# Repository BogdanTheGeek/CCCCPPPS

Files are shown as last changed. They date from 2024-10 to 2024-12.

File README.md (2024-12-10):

# Cheap Crappy Constant Current Portable Programmable Power Supply 

`CCCCPPPS` is a DIY Programmable Buck/Boost Power Supply, designed with the goal
of being cheap, crappy, but very useful!  

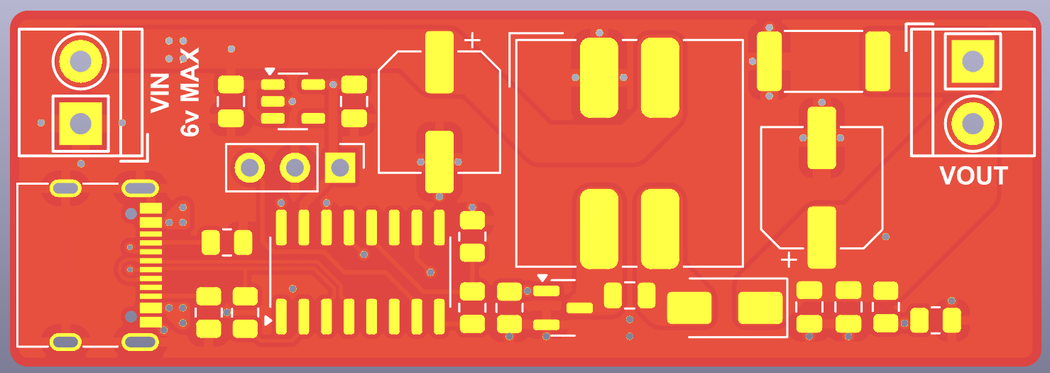
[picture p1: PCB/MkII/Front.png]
PCB_Front
  
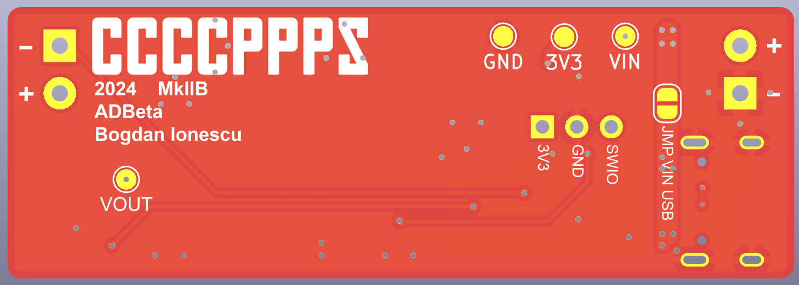
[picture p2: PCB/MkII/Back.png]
PCB_Back
  
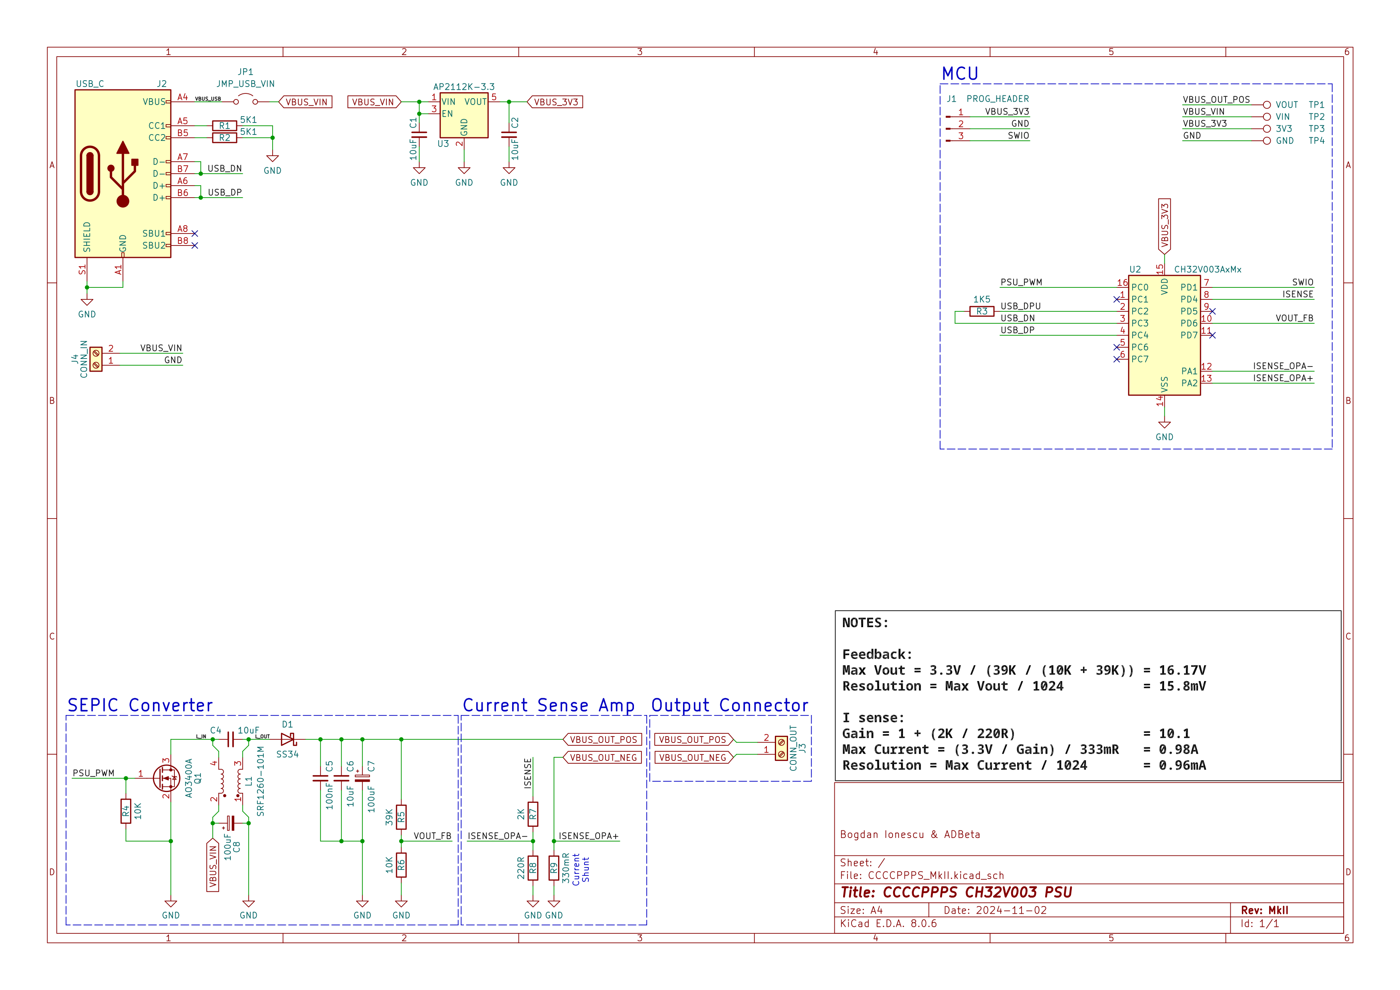
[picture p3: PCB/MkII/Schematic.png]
PCB_Schem
  

# Usage
## Web UI
https://bogdanthegeek.github.io/CCCCPPPS/software/webui/index.html
## Debug Interface:
This interface is enabled by default when building the firmware. Use `minichlink`
to issue commands listed below

## Commands
> [!NOTE]
> Need to improve the command list and handler

- `0` to turn the supply off
- `1-9` to set the target Voltage/Current in multiples of 1000mV/100mA
- `c` to switch to Constant Current Mode 
- `v` to switch to Constant Voltage Mode
- `+` to increase the target Voltage/Current depending on mode, in 50mV/25mA increments
- `-` to decrease the target Voltage/Current depending on mode, in 50mV/25mA increments
- ~~Konami code makes the unit self distruct.~~ Removed due to misuse.

# Build
```sh
export CH32V003FUN="path/to/ch32v003fun"
make
```

----
(c) 2024  
[Bogdan Ionescu](https://github.com/BogdanTheGeek)  
[ADBeta](https://github.com/ADBeta)

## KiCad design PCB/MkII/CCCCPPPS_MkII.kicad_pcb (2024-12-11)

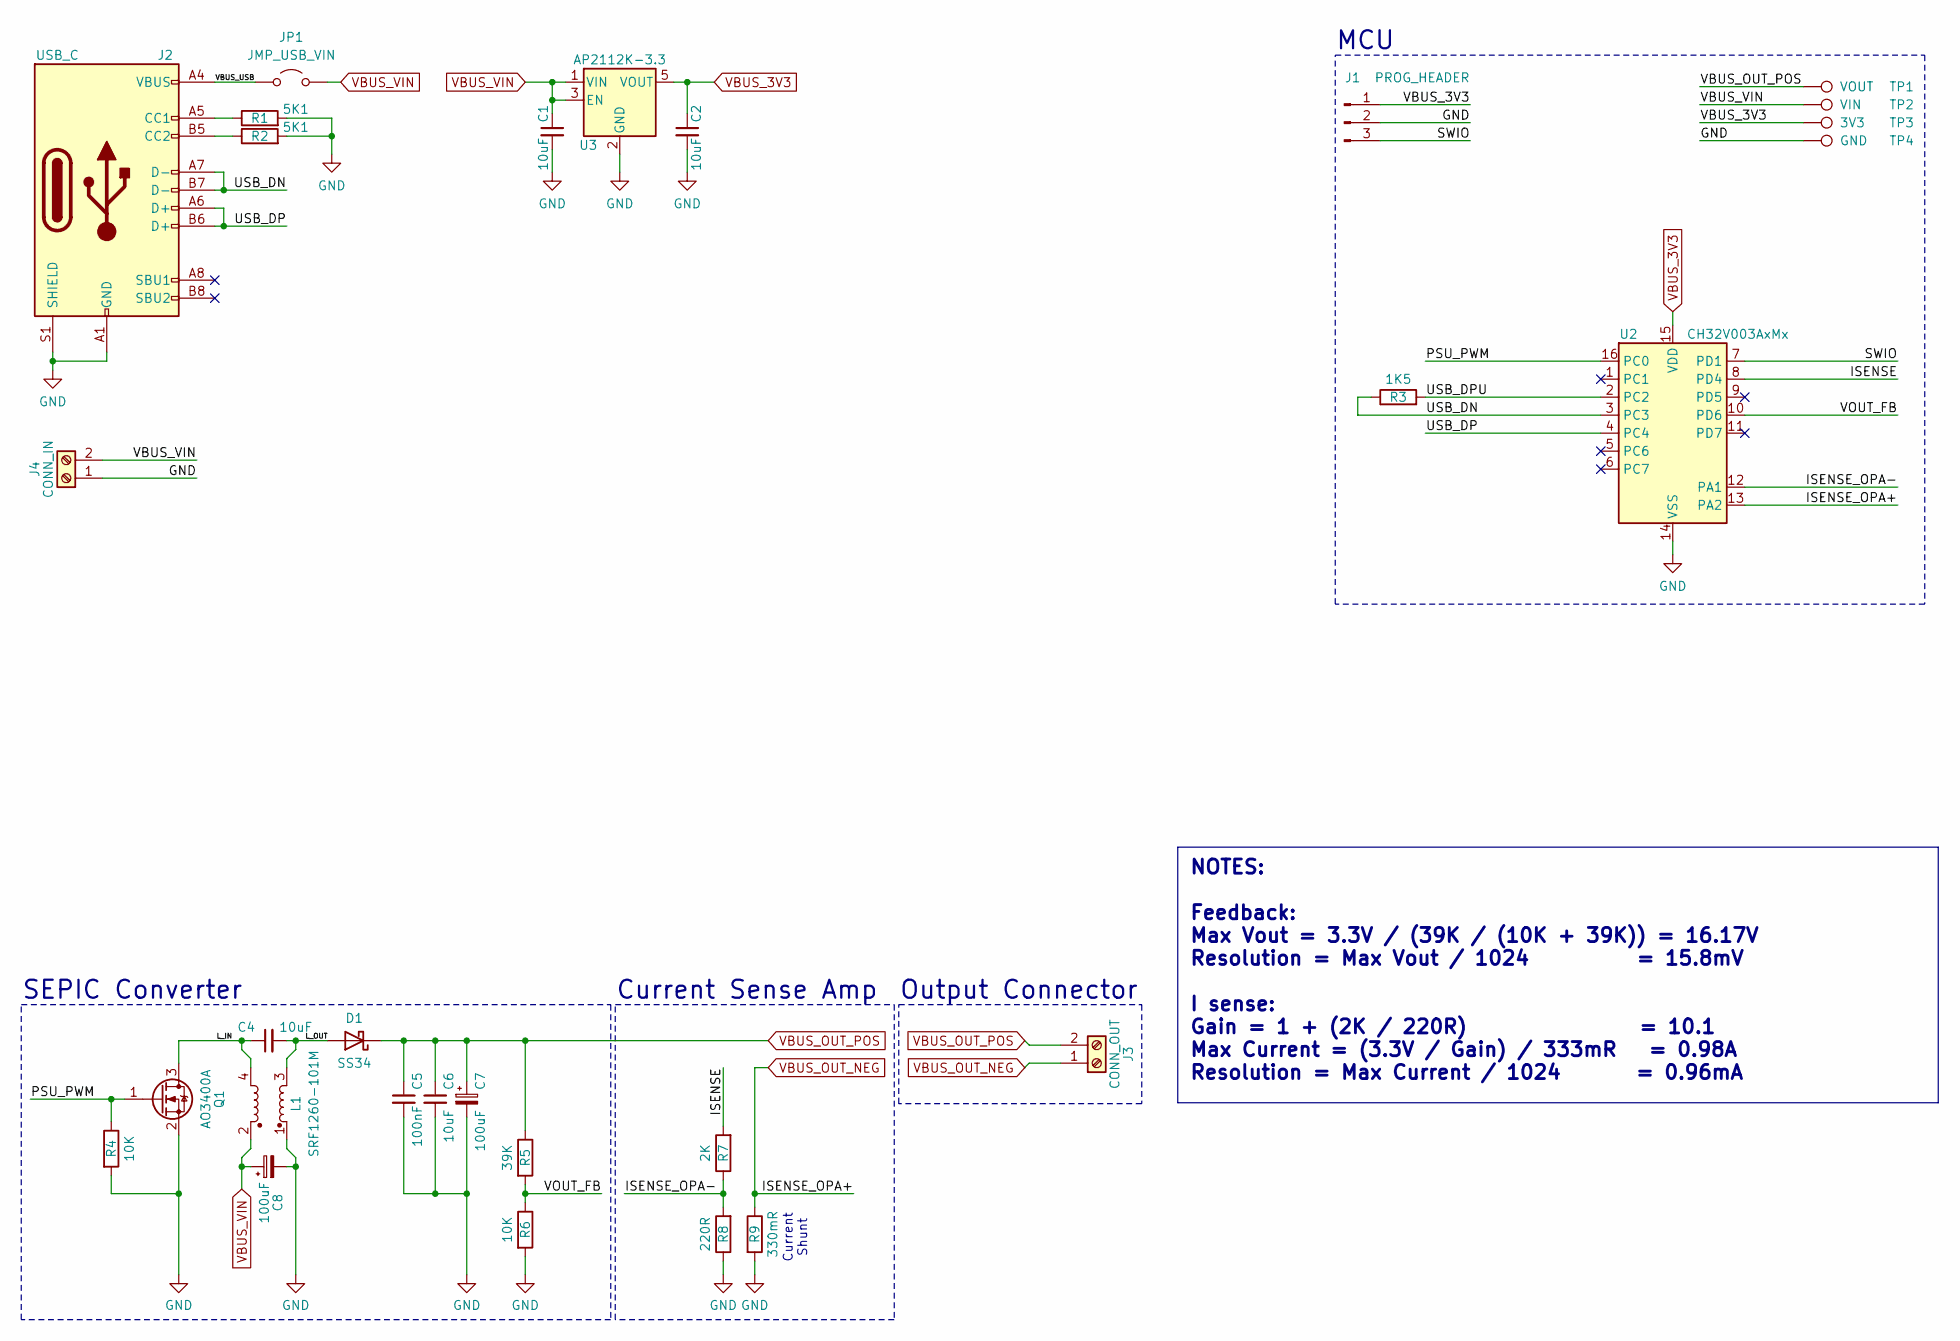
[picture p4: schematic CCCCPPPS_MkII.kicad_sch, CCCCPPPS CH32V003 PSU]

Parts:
C1, C2, C4, C6: 10uF; C_0805_2012Metric
C5: 100nF; C_0805_2012Metric
C7, C8: 100uF; CP_Elec_6.3x5.2
D1: SS34; D_SMA
J1: PROG_HEADER; PinHeader_1x03_P2.54mm_Vertical
J2: USB_C; USB_C_Receptacle_G-Switch_GT-USB-7010ASV
J3: CONN_OUT; PCB_Terminal_Block_2-P3.5
J4: CONN_IN; PCB_Terminal_Block_2-P3.5
JP1: JMP_USB_VIN; SolderJumper-2_P1.3mm_Open_RoundedPad1.0x1.5mm
L1: SRF1260-101M; L_Bourns_SRF1260
Q1: AO3400A; SOT-23
R1, R2: 5K1; R_0805_2012Metric
R3: 1K5; R_0805_2012Metric
R4, R6: 10K; R_0805_2012Metric
R5: 39K; R_0805_2012Metric
R7: 2K; R_0805_2012Metric
R8: 220R; R_0805_2012Metric
R9: 330mR; R_2512_6332Metric_Pad1.40x3.35mm_HandSolder
TP1: VOUT; TestPoint_Pad_D1.5mm
TP2: VIN; TestPoint_Pad_D1.5mm
TP3: 3V3; TestPoint_Pad_D1.5mm
TP4: GND; TestPoint_Pad_D1.5mm
U2: CH32V003AxMx; SOP-16_3.9x9.9mm_P1.27mm
U3: AP2112K-3.3; SOT-23-5

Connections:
/ISENSE: R7.2, U2.8 (PD4)
/ISENSE_OPA-: R7.1, R8.2, U2.12 (PA1)
/L_IN: C4.1, L1.4, Q1.3 (D)
/L_OUT: C4.2, D1.2 (A), L1.3
/PSU_PWM: Q1.1 (G), R4.1, U2.16 (PC0)
/SWIO: J1.3, U2.7 (PD1)
/USB_DN: J2.A7 (D-), J2.B7 (D-), R3.1, U2.3 (PC3)
/USB_DP: J2.A6 (D+), J2.B6 (D+), U2.4 (PC4)
/USB_DPU: R3.2, U2.2 (PC2)
/VBUS_USB: J2.A4 (VBUS), J2.A9 (VBUS), J2.B4 (VBUS), J2.B9 (VBUS), JP1.1 (A)
/VOUT_FB: R5.2, R6.1, U2.10 (PD6)
GND: C1.2, C2.2, C5.2, C6.2, C7.2, C8.2, J1.2, J2.A1 (GND), J2.A12 (GND), J2.B1 (GND), J2.B12 (GND), J2.S1 (SHIELD), J4.1, L1.1, Q1.2 (S), R1.2, R2.2, R4.2, R6.2, R8.1, R9.2, TP4.1, U2.14 (VSS), U3.2 (GND)
unnamed: J2.A5 (CC1), R1.1
unnamed: J2.B5 (CC2), R2.1
VBUS_3V3: C2.1, J1.1, TP3.1, U2.15 (VDD), U3.5 (VOUT)
VBUS_OUT_NEG: J3.1, R9.1, U2.13 (PA2)
VBUS_OUT_POS: C5.1, C6.1, C7.1, D1.1 (K), J3.2, R5.1, TP1.1
VBUS_VIN: C1.1, C8.1, J4.2, JP1.2 (B), L1.2, TP2.1, U3.1 (VIN), U3.3 (EN)

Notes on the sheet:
NOTES: Feedback: Max Vout = 3.3V / (39K / (10K + 39K)) = 16.17V Resolution = Max Vout / 1024 = 15.8mV I sense: Gain = 1 + (2K / 220R) = 10.1 Max Current = (3.3V / Gain) / 333mR = 0.98A Resolution = Max Current / 1024 = 0.96mA
MCU
Output Connector
Current Shunt
SEPIC Converter
Current Sense Amp

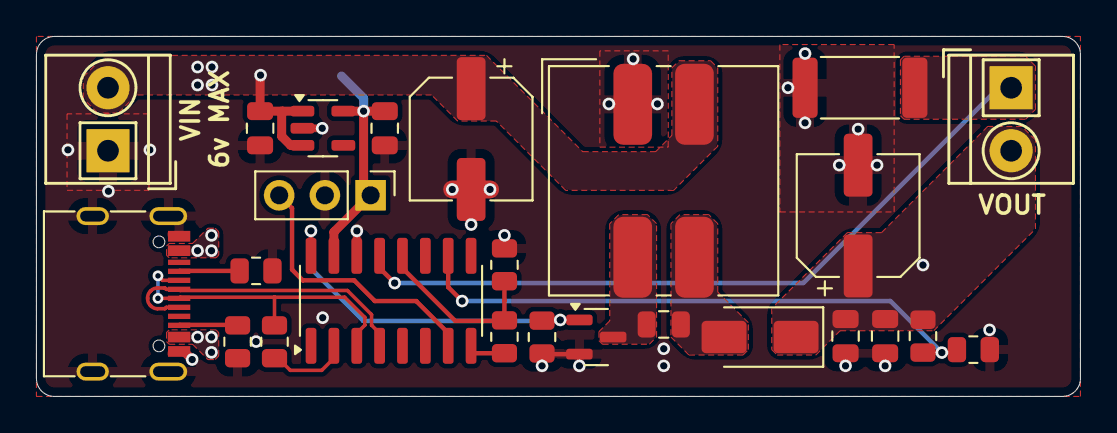
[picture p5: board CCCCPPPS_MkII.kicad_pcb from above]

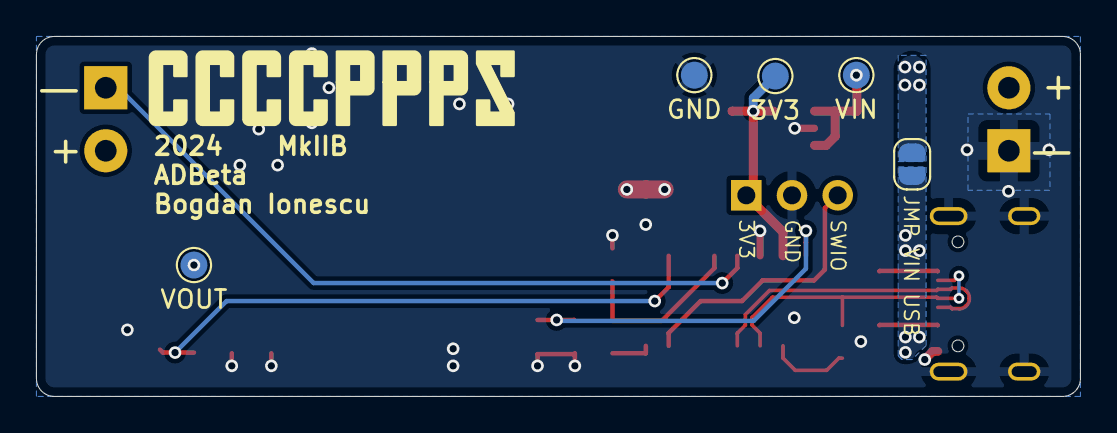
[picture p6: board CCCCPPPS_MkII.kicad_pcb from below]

Board: 2 copper layers, 58.0 x 20.0 mm, 30 parts (5 on the bottom side), 18 nets.

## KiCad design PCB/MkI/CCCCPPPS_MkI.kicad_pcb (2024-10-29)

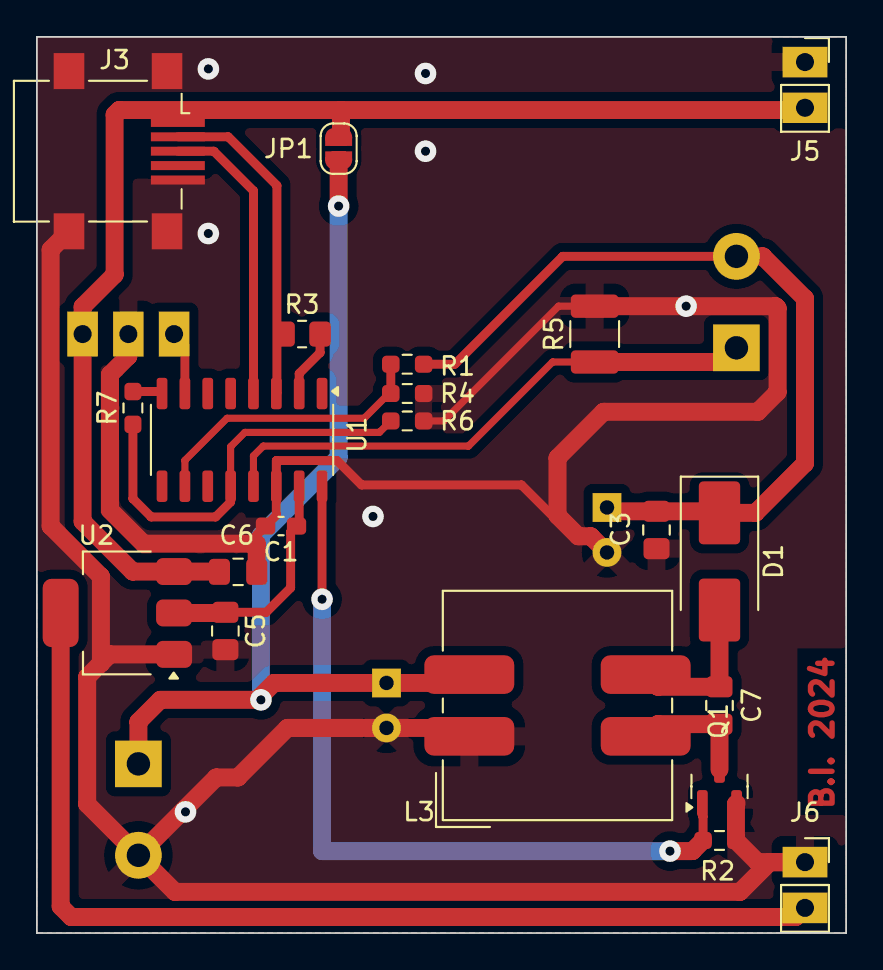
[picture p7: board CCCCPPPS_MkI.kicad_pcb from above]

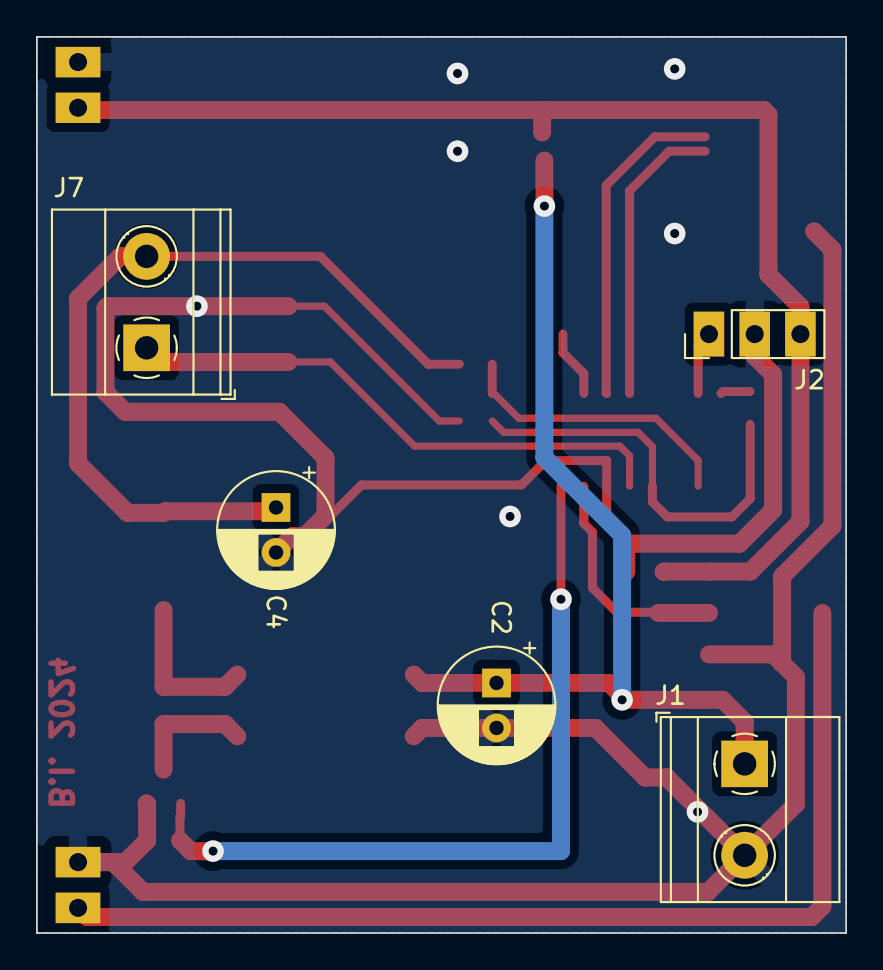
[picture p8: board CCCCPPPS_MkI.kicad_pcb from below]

Board: 2 copper layers, 45.0 x 49.8 mm, 26 parts (5 on the bottom side), 16 nets.

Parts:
C1: 0.1uF; C_0603_1608Metric_Pad1.08x0.95mm_HandSolder
C2: 100uF; CP_Radial_D6.3mm_P2.50mm
C3, C6, C7: 10uF; C_0805_2012Metric_Pad1.18x1.45mm_HandSolder
C4: 100uF 25V; CP_Radial_D6.3mm_P2.50mm
C5: 1uF; C_0805_2012Metric_Pad1.18x1.45mm_HandSolder
D1: B2100-13-F; D_SMB_Handsoldering
J1, J7: Screw_Terminal_01x02; TerminalBlock_Phoenix_MKDS-1,5-2-5.08_1x02_P5.08mm_Horizont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
J2: PROG; PinHeader_1x03_P2.54mm_Vertical
J3: USB_B_Mini; USB_Mini-B_Lumberg_2486_01_Horizontal
J5, J6: Conn_01x02; PinSocket_1x02_P2.54mm_Vertical
JP1: SolderJumper_2_Open; SolderJumper-2_P1.3mm_Open_RoundedPad1.0x1.5mm
L3: SRF1260-101M; L_Bourns_SRF1260
Q1: AO3400A; SOT-23
R1: 39k; R_0603_1608Metric_Pad0.98x0.95mm_HandSolder
R2, R4: 10k; R_0603_1608Metric_Pad0.98x0.95mm_HandSolder
R3: 1K5; R_0805_2012Metric_Pad1.20x1.40mm_HandSolder
R5: 333mΩ; R_1210_3225Metric_Pad1.30x2.65mm_HandSolder
R6: 220R; R_0603_1608Metric_Pad0.98x0.95mm_HandSolder
R7: 2k; R_0603_1608Metric_Pad0.98x0.95mm_HandSolder
U1: CH32V003A4M6; SO-16_3.9x9.9mm_P1.27mm
U2: AZ1117-3.3; SOT-223-3_TabPin2

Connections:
+3V3: C1.1, C5.1, J6.2, U1.15 (VDD), U2.2 (VO)
+5V: C6.1, J2.3, J3.1 (VBUS), J5.2, JP1.2 (B), U2.3 (VI)
/VOUT+: C3.1, C4.1, D1.1 (K), J7.2, R1.1
GND: C1.2, C2.2, C3.2, C4.2, C5.2, C6.2, J1.2, J2.2, J3.5 (GND), J3.6 (Shield), J5.1, J6.1, L3.1, Q1.2 (S), R2.2, R4.2, R5.2, R6.1, U1.14 (vss), U2.1 (GND)
unnamed: C7.2, D1.2 (A), L3.3
unnamed: C7.1, L3.4, Q1.3 (D)
PA1: R6.2, R7.1, U1.12 (PA1_A1_T1CH2_OSCI)
PA2: J7.1, R5.1, U1.13 (PA2_A0_T1CH2N_OSCO)
PC0: Q1.1 (G), R2.1, U1.16 (PC0_T2CH3)
PC2: R3.1, U1.2 (PC2_SCL)
PC3: J3.2 (D-), R3.2, U1.3 (PC3)
PC4: J3.3 (D+), U1.4 (PC4_A2_T1CH4)
PD4: R7.2, U1.8 (PD4_A7_T2AETR2)
PD6: R1.2, R4.1, U1.10 (PD6_A6_UART_RX)
SWIO: J2.1, U1.7 (SWIO&PD1_T1CH3N)
VPP: C2.1, J1.1, JP1.1 (A), L3.2

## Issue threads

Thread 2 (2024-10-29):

Add CCCV mode

BogdanTheGeek, 2024-10-29:
Currently, the constant current mode doesn't respect the voltage limit or vice-versa.

I think this could be achieved by picking the smallest duty cycle returned by the CV and CC algorithms.

Closed 2024-11-02.

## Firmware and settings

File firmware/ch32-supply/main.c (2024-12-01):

//------------------------------------------------------------------------------
//       Filename: main.c
//------------------------------------------------------------------------------
//       Bogdan Ionescu (c) 2024
//------------------------------------------------------------------------------
//       Purpose : Application entry point
//------------------------------------------------------------------------------
//       Notes : None
//------------------------------------------------------------------------------

//------------------------------------------------------------------------------
// Module includes
//------------------------------------------------------------------------------
#include <inttypes.h>
#include <stdbool.h>

#include "boost.h"
#include "ch32v003fun.h"
#include "log.h"
#include "nvs.h"
#include "rv003usb.h"

//------------------------------------------------------------------------------
// Module constant defines
//------------------------------------------------------------------------------

#define TAG "main"

#ifndef CONFIG_CURRENT_LIMIT
#define CONFIG_CURRENT_LIMIT 1000
#endif

#ifndef CONFIG_VOLTAGE_LIMIT
#define CONFIG_VOLTAGE_LIMIT 15000
#endif

#define NVS_MAGIC 0xbee5

#define array_size(x) (sizeof(x) / sizeof(x[0]))
//------------------------------------------------------------------------------
// External variables
//------------------------------------------------------------------------------

//------------------------------------------------------------------------------
// External functions
//------------------------------------------------------------------------------

//------------------------------------------------------------------------------
// Module type definitions
//------------------------------------------------------------------------------

typedef struct
{
    uint32_t voltage;
    uint32_t current;
    uint16_t magic;
    bool save;
} Settings_t;

typedef enum
{
    CMD_SET_VOLTAGE = 1,
    CMD_SET_CURRENT = 2,
    CMD_SAVE = 3,
} CommandId_e;

//------------------------------------------------------------------------------
// Module static variables
//------------------------------------------------------------------------------
static volatile uint32_t s_systickCount = 0;

static volatile size_t s_bytesReceived = 0;
static volatile Settings_t s_settings = {
    .voltage = 0,
    .current = CONFIG_CURRENT_LIMIT,
};
static volatile BoostState_t s_state = {
    .voltage = 0,
    .current = CONFIG_CURRENT_LIMIT,
    .duty = 0,
    .ccMode = false,
};

//------------------------------------------------------------------------------
// Module static function prototypes
//------------------------------------------------------------------------------
static void SysTick_Init(void);
static void WDT_Init(uint16_t reload_val, uint8_t prescaler);
static void WDT_Pet(void);

//------------------------------------------------------------------------------
// Module externally exported functions
//------------------------------------------------------------------------------

/**
 * @brief  Application entry point
 * @param  None
 * @return None
 */
int main(void)
{
    SystemInit();

    SysTick_Init();

    const bool debuggerAttached = !WaitForDebuggerToAttach(1000);
    if (debuggerAttached)
    {
        LOG_Init(eLOG_LEVEL_INFO, (uint32_t *)&s_systickCount);
    }
    else
    {
        LOG_Init(eLOG_LEVEL_NONE, (uint32_t *)&s_systickCount);
    }

#ifdef CONFIG_USE_USB
    usb_setup();
#endif

    NVS_Init();

    NVS_Load((uint8_t *)&s_settings, 0, sizeof(s_settings));

    if (s_settings.magic != NVS_MAGIC)
    {
        LOGE(TAG, "Invalid settings(0x%x), resetting to defaults", s_settings.magic);
        s_settings.voltage = 0;
        s_settings.current = CONFIG_CURRENT_LIMIT;
        s_settings.magic = NVS_MAGIC;
        s_settings.save = false;
    }

    LOGI(TAG, "Voltage: %dmV, Current: %dmA", s_settings.voltage, s_settings.current);

    BoostPWM_Init();

    BoostPWM_SetVoltageTarget(s_settings.voltage);
    BoostPWM_SetCurrentLimit(s_settings.current);

#if 0

    for (size_t i = 1000; i < 5001; i += 200)
    {
        BoostPWM_SetVoltageTarget(i);
        LOGD(TAG, "Target: %dmV", i);
        Delay_Ms(100);
    }
#endif

    WDT_Init(0x0FFF, IWDG_Prescaler_128);

    static uint32_t power = 0;

    static size_t s_lastBytesReceived = 0;
    static uint32_t lastTime = 0;

    while (1)
    {
        WDT_Pet();

        if (s_bytesReceived != s_lastBytesReceived)
        {
            LOGD(TAG, "Received %d bytes", s_bytesReceived - s_lastBytesReceived);
            LOGI(TAG, "Setting Voltage: %dmV, Current: %dmA", s_settings.voltage, s_settings.current);

            if (s_settings.voltage > CONFIG_VOLTAGE_LIMIT)
            {
                s_settings.voltage = CONFIG_VOLTAGE_LIMIT;
            }

            if (s_settings.current > CONFIG_CURRENT_LIMIT)
            {
                s_settings.voltage = CONFIG_CURRENT_LIMIT;
            }

            BoostPWM_SetVoltageTarget(s_settings.voltage);
            BoostPWM_SetCurrentLimit(s_settings.current);
            s_lastBytesReceived = s_bytesReceived;
        }

        if (s_settings.save)
        {
            s_settings.save = false;
            LOGI(TAG, "Saving settings: Voltage: %dmV, Current: %dmA",
                 s_settings.voltage, s_settings.current);
            NVS_Save((uint8_t *)&s_settings, sizeof(s_settings));
            LOGI(TAG, "Settings saved");

            // NOTE: no idea why, but systick skips an interrupt after this
            SysTick_Init();
            LOGI(TAG, "SysTick restarted");
        }

        BoostPWM_GetState((BoostState_t *)&s_state);
        power = (s_state.voltage * s_state.current) / 1000;

        if (s_systickCount - lastTime > 1000)
        {
            lastTime = s_systickCount;
            LOGI(TAG, "CC: %d, Voltage: %5dmV, Current: %4dmA, Power: %5dmW, Duty: %3d",
                 s_state.ccMode,
                 s_state.voltage,
                 s_state.current,
                 power,
                 s_state.duty);
        }

        if (!debuggerAttached) continue;

        int c = getchar();

        switch (c)
        {
            case '0':
                BoostPWM_SetVoltageTarget(0);
                BoostPWM_SetCurrentLimit(CONFIG_CURRENT_LIMIT);
                s_settings.voltage = 0;
                s_settings.current = CONFIG_CURRENT_LIMIT;
                break;
            case '+':
            case '=':
                if (s_state.ccMode)
                {
                    s_settings.current += 25;
                    BoostPWM_SetCurrentLimit(s_settings.current);
                }
                else
                {
                    s_settings.voltage += 50;
                    BoostPWM_SetVoltageTarget(s_settings.voltage);
                }
                break;
            case '-':
                if (s_state.ccMode)
                {
                    s_settings.current -= 25;
                    BoostPWM_SetCurrentLimit(s_settings.current);
                }
                else
                {
                    s_settings.voltage -= 50;
                    BoostPWM_SetVoltageTarget(s_settings.voltage);
                }
                break;
            case -1:
                break;
            case 'c':
                s_state.ccMode = true;
                break;
            case 'v':
                s_state.ccMode = false;
                break;
            case 's':
                s_settings.save = true;
                break;
            default:
                if (c <= '0' || c > '9') break;
                if (s_state.ccMode)
                {
                    s_settings.current = (c - '0') * 100;
                    BoostPWM_SetCurrentLimit(s_settings.current);
                }
                else
                {
                    s_settings.voltage = (c - '0') * 1000;
                    BoostPWM_SetVoltageTarget(s_settings.voltage);
                }
                break;
        }
        Delay_Ms(100);
    }
}

//------------------------------------------------------------------------------
// Module static functions
//------------------------------------------------------------------------------

/**
 * @brief  Enable the SysTick module
 * @param  None
 * @return None
 */
static void SysTick_Init(void)
{
    // Disable default SysTick behavior
    SysTick->CTLR = 0;

    // Enable the SysTick IRQ
    NVIC_EnableIRQ(SysTicK_IRQn);

    // Set the tick interval to 1ms for normal op
    SysTick->CMP = (FUNCONF_SYSTEM_CORE_CLOCK / 1000) - 1;

    // Start at zero
    SysTick->CNT = 0;
    s_systickCount = 0;

    // Enable SysTick counter, IRQ, HCLK/1
    SysTick->CTLR = SYSTICK_CTLR_STE | SYSTICK_CTLR_STIE | SYSTICK_CTLR_STCLK;
}

/**
 * @brief  Initialize the watchdog timer
 * @param reload_val - the value to reload the counter with
 * @param prescaler - the prescaler to use
 * @return None
 */
static void WDT_Init(uint16_t reload_val, uint8_t prescaler)
{
    IWDG->CTLR = 0x5555;
    IWDG->PSCR = prescaler;

    IWDG->CTLR = 0x5555;
    IWDG->RLDR = reload_val & 0xfff;

    IWDG->CTLR = 0xCCCC;
}

/**
 * @brief  Pet the watchdog timer
 * @param  None
 * @return None
 */
static void WDT_Pet(void)
{
    IWDG->CTLR = 0xAAAA;
}

/**
 * @brief  SysTick interrupt handler
 * @param  None
 * @return None
 * @note   __attribute__((interrupt)) syntax is crucial!
 */
void SysTick_Handler(void) __attribute__((interrupt));
void SysTick_Handler(void)
{
    // Set the next interrupt to be in 1/1000th of a second
    SysTick->CMP += (FUNCONF_SYSTEM_CORE_CLOCK / 1000);

    // Clear IRQ
    SysTick->SR = 0;

    // Update counter
    s_systickCount++;
}

/**
 * @brief  Handle USB user in requests
 * @param  e - the endpoint
 * @param  scratchpad - the scratchpad buffer
 * @param  endp - the endpoint number
 * @param  sendtok - the token to send
 * @param  ist - the internal state
 * @return None
 * @note usb_hande_interrupt_in is OBLIGATED to call usb_send_data or usb_send_empty.
 */
void usb_handle_user_in_request(struct usb_endpoint *e, uint8_t *scratchpad, int endp, uint32_t sendtok, struct rv003usb_internal *ist)
{
    // Make sure we only deal with control messages. Like get/set feature reports.
    if (endp)
    {
        usb_send_empty(sendtok);
    }
}

/**
 * @brief  Handle USB control messages
 * @param  e - the endpoint
 * @param  s - the URB
 * @param  ist - the internal state
 * @return None
 */
void usb_handle_other_control_message(struct usb_endpoint *e, struct usb_urb *s, struct rv003usb_internal *ist)
{
    LogUEvent(SysTick->CNT, s->wRequestTypeLSBRequestMSB, s->lValueLSBIndexMSB, s->wLength);
    // e->opaque = (uint8_t *)1;
}

/**
 * @brief  Handle USB user data
 * @param      e - the endpoint
 * @param      current_endpoint - the current endpoint
 * @param[in]  data - the data
 * @param      len - the length
 * @param      ist - the internal state
 * @return None
 */
void usb_handle_user_data(struct usb_endpoint *e, int current_endpoint, uint8_t *data, int len, struct rv003usb_internal *ist)
{
#if 0
    int offset = e->count << 3;
    int torx = e->max_len - offset;
    if (torx > len) torx = len;
	if( torx > 0 )
	{
		memcpy( scratch + offset, data, torx );
		e->count++;

      s_bytesReceived += torx;
	}
#else
    if (len >= 6 && 0xAA == data[0])
    {
        const uint8_t cmd = data[1];
        switch (cmd)
        {
            case CMD_SET_VOLTAGE:
                s_settings.voltage = *(uint32_t *)(data + 2);
                break;
            case CMD_SET_CURRENT:
                s_settings.current = *(uint32_t *)(data + 2);
                break;
            case CMD_SAVE:
                s_settings.save = true;
                break;
        }

        e->count++;
        s_bytesReceived += len;
    }
#endif
}

void usb_handle_hid_get_report_start(struct usb_endpoint *e, int reqLen, uint32_t lValueLSBIndexMSB)
{

    // You can check the lValueLSBIndexMSB word to decide what you want to do here
    // But, whatever you point this at will be returned back to the host PC where
    // it calls hid_get_feature_report.
    //
    // Please note, that on some systems, for this to work, your return length must
    // match the length defined in HID_REPORT_COUNT, in your HID report, in usb_config.h

    // if (reqLen > sizeof(s_state)) reqLen = sizeof(s_state);
    e->opaque = (void *)&s_state;
    e->max_len = sizeof(s_state);
}

void usb_handle_hid_set_report_start(struct usb_endpoint *e, int reqLen, uint32_t lValueLSBIndexMSB)
{
    // Here is where you get an alert when the host PC calls hid_send_feature_report.
    //
    // You can handle the appropriate message here.  Please note that in this
    // example, the data is chunked into groups-of-8-bytes.
    //
    // Note that you may need to make this match HID_REPORT_COUNT, in your HID
    // report, in usb_config.h

    // if (reqLen > sizeof(s_state)) reqLen = sizeof(s_state);
    e->max_len = sizeof(s_state);
}

static uint8_t newByte = 0;
static uint32_t count = 0;
static uint32_t countLast = 0;

/**
 * @brief  Debugger input handler
 * @param  numbytes - the number of bytes received
 * @param  data - the data (8 bytes)
 * @return None
 */
void handle_debug_input(int numbytes, uint8_t *data)
{
    newByte = data[0];
    count += numbytes;
}

/**
 * @brief  Get the next character from the debugger
 * @param  None
 * @return the next character or -1 if no character is available
 * @note   This function will block for up to 100ms waiting for a character
 */
int getchar(void)
{
    const uint32_t timeout = 100;
    const uint32_t end = s_systickCount + timeout;
    while (count == countLast && (s_systickCount < end))
    {
        poll_input();
        putchar(0);
    }

    if (count == countLast)
    {
        return -1;
    }

    countLast = count;
    return newByte;
}

//------------------------------------------------------------------------------
//------------------------------------------------------------------------------
//------------------------------------------------------------------------------

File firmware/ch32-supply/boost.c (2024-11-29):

//------------------------------------------------------------------------------
//       Filename: boost.c
//------------------------------------------------------------------------------
//       Bogdan Ionescu (c) 2024
//------------------------------------------------------------------------------
//       Purpose : Implements the Boost Converter API
//------------------------------------------------------------------------------
//       Notes : None
//------------------------------------------------------------------------------
//
// PWM_OUT = PC0 = T1CH3
// FEEDBACK = PD6 = A6
// CURRENT = PD4 = A7
//
//------------------------------------------------------------------------------
// Module includes
//------------------------------------------------------------------------------
#include "boost.h"
#include "ch32v003fun.h"
#include "log.h"

//------------------------------------------------------------------------------
// Module constant defines
//------------------------------------------------------------------------------
#define TAG "boost"

// Feedback Resistors in 10 Ohm units
#define Rf  390
#define Rin 100
#define Rt  (Rf + Rin)

#define INTERNAL_VREF  1200
#define ADC_RESOLUTION 10
#define ADC_MAX        (1 << ADC_RESOLUTION)

#define MIN_DUTY    0
#define MAX_DUTY    250
#define ADC_SAMPLES (3)

// PID terms
#define KP(eP) ((eP) >> 0)
#define KD(eD) ((eD) >> 3)
#define KI(eI) ((eI) >> 6)

#ifndef min
#define min(a, b) (((a) < (b)) ? (a) : (b))
#endif
#ifndef max
#define max(a, b) (((a) > (b)) ? (a) : (b))
#endif

#ifndef INLINE
#define INLINE __attribute__((always_inline))
#endif

//------------------------------------------------------------------------------
// External variables
//------------------------------------------------------------------------------

//------------------------------------------------------------------------------
// External functions
//------------------------------------------------------------------------------

//------------------------------------------------------------------------------
// Module type definitions
//------------------------------------------------------------------------------

//------------------------------------------------------------------------------
// Module static variables
//------------------------------------------------------------------------------
static uint16_t s_feedbackVRaw = 0;
static uint16_t s_feedbackIRaw = 0;
static int16_t s_currentOffset = 0;
static uint16_t s_vref = 0;
static uint8_t s_pwmDuty = 0;
static uint8_t s_ccMode = 0;
static volatile uint32_t s_targetVRaw = 0;
static volatile uint32_t s_targetIRaw = 0;

//------------------------------------------------------------------------------
// Module static function prototypes
//------------------------------------------------------------------------------
static int GetVRefMillivolts(void);
static uint16_t GetVoltageMillivolts(void);
static uint16_t MillivoltsToADC(uint32_t millivolts);
static uint16_t GetCurrentMilliamps(void);
static uint16_t MilliampsToADC(uint32_t milliamps);

static void SetupOpAmp(void);
static void SetupADC(void);

static void BoostControllerPID(void);
static void SetDuty(uint8_t duty);

static void Calibrate(void);

//------------------------------------------------------------------------------
// Module externally exported functions
//------------------------------------------------------------------------------
/**
 * @brief  Initialize the Boost converter
 * @param  None
 * @return None
 */
void BoostPWM_Init(void)
{
    SetupOpAmp();

    SetupADC();

    RCC->APB2PCENR |= RCC_APB2Periph_TIM1 | RCC_APB2Periph_AFIO | RCC_APB2Periph_GPIOC;

    AFIO->PCFR1 |= GPIO_PartialRemap1_TIM1;

    // PC0 is T1CH3, 10MHz Output alt func, push-pull
    GPIOC->CFGLR &= ~(0xf << (0 << 2));
    GPIOC->CFGLR |= (GPIO_Speed_10MHz | GPIO_CNF_OUT_PP_AF) << (0 << 2);

    // Reset TIM1 to init all regs
    RCC->APB2PRSTR |= RCC_APB2Periph_TIM1;
    RCC->APB2PRSTR &= ~RCC_APB2Periph_TIM1;

    // CTLR1: default is up, events generated, edge align
    // SMCFGR: default clk input is CK_INT

    // Prescaler
    TIM1->PSC = 0x0001;

    // Auto Reload - sets period
    TIM1->ATRLR = 255 + 10;

    // Reload immediately
    TIM1->SWEVGR |= TIM_UG;

    // Enable CH3 output, normal polarity
    TIM1->CCER |= TIM_CC3E | TIM_CC3NP;

    // CH3 Mode is output, PWM1 (CC3S = 00, OC3M = 110)
    TIM1->CHCTLR2 |= TIM_OC3M_2 | TIM_OC3M_1;

    // Set the Capture Compare Register value to off
    TIM1->CH3CVR = 0;

    // Setup TRGO for ADC.  This makes is to the ADC will trigger on timer
    // reset, so we trigger at the same position every time relative to the
    // FET turning on.
    TIM1->CTLR2 = TIM_MMS_1;

    // Enable TIM1 outputs
    TIM1->BDTR |= TIM_MOE;

    // Enable TIM1
    TIM1->CTLR1 |= TIM_CEN;

    Calibrate();

#if 0

    LOGD(TAG, "VRef: (%d) %dmV", s_vref, GetVRefMillivolts());
    LOGD(TAG, "Vout: (%d) %dmV", s_feedbackRaw, GetVoltageMillivolts());
    LOGD(TAG, "Current: (%d) %dmA", s_current, GetCurrentMilliamps());
    LOGD(TAG, "Target: %d", s_targetADC);
    puts("");
    Delay_Ms(1000);
#endif
}

/**
 * @brief  Set the target voltage for the boost converter
 * @param millivolts - The target voltage in millivolts
 * @return None
 */
void BoostPWM_SetVoltageTarget(uint32_t millivolts)
{
    s_targetVRaw = MillivoltsToADC(millivolts);
}

/**
 * @brief  Set the current limit for the boost converter
 * @param  milliamps - The current limit in milliamps, 0 to disable
 * @return None
 */
void BoostPWM_SetCurrentLimit(uint32_t milliamps)
{
    if (milliamps > 0)
    {
        s_targetIRaw = MilliampsToADC(milliamps);
    }
    else
    {
        s_targetIRaw = 0;
    }
}

/**
 * @brief  Get the state of the boost converter
 * @param[out] state - The state of the boost converter
 * @return None
 */
void BoostPWM_GetState(BoostState_t *state)
{
    *state = (BoostState_t){
        .voltage = GetVoltageMillivolts(),
        .current = GetCurrentMilliamps(),
        .duty = s_pwmDuty,
        .ccMode = s_ccMode,
    };
}

/**
 * @brief  ADC1 IRQ Handler
 * @param  None
 * @return None
 */
void ADC1_IRQHandler(void) __attribute__((section(".srodata"))) __attribute__((interrupt));
void ADC1_IRQHandler(void)
{
    // Values come in reverse order.
    s_vref = ADC1->IDATAR2;
    s_feedbackIRaw = ADC1->IDATAR1;

    s_feedbackVRaw = ADC1->RDATAR;
    BoostControllerPID();

    // Acknowledge pending interrupts.
    ADC1->STATR = 0;
}

//------------------------------------------------------------------------------
// Module static functions
//------------------------------------------------------------------------------

/**
 * @brief  Get the VRef voltage in millivolts
 * @param  None
 * @return The VRef voltage in millivolts
 */
static int GetVRefMillivolts(void)
{
    return ((INTERNAL_VREF * ADC_MAX) / s_vref);
}
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

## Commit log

2024-11-02 main: boost: switch to limit PID control
2024-11-29 firmware: webui: fix windows
    [boost.c, main.c]
2024-12-10 MkII PCB and Updated README
    [CCCCPPPS_MkI.kicad_pcb, CCCCPPPS_MkI.kicad_sch, CCCCPPPS_MkII.kicad_pcb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]
2024-12-11 Fixed MkII USB and Polarity issues. MkIIB
    [CCCCPPPS_MkII.kicad_pcb]
2024-12-11 Updated PCB Images
2024-12-11 Fixed Polarity Marking, for real this time :)
    [CCCCPPPS_MkII.kicad_pcb]
